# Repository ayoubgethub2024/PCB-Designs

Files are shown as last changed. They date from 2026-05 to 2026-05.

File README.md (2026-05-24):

## PCB Specifications

| Parameter | Specification |
|---|---|
| Microcontroller 1 | ATmega328P (DIP-28 or SMD) |
| Microcontroller 2 | ESP8266 (ESP-12E/F module) |
| Input Voltage | 12-24V DC (industrial standard) |
| Regulated Output | 5V @ 2A, 3.3V @ 800mA |
| Digital Inputs | 6x opto-isolated (24V) |
| Digital Outputs | 4x relay outputs (10A 250VAC) |
| Analog Inputs | 4x (0-5V / 4-20mA selectable) |
| Communication | UART, Modbus RS-485 (optional) |
| PCB Layers | 2-layer |
| PCB Size | 100mm x 80mm |

## Key Components

| Component | Part Number | Function |
|---|---|---|
| ATmega328P | ATMEGA328P-PU | Main sensor processor |
| ESP8266 | ESP-12E | WiFi and web server |
| Voltage Regulator | LM2596 | 12V to 5V conversion |
| LDO | AMS1117-3.3 | 5V to 3.3V for ESP |
| Optocoupler | PC817 | Input isolation |
| Relay | SRD-05VDC-SL-C | Output switching |
| RS-485 Transceiver | MAX485 | Modbus communication |

## File Descriptions

| File | Description |
|---|---|
| `schematic.pdf` | Complete circuit schematic |
| `pcb_layout.pdf` | PCB layout (top and bottom layers) |
| `gerber_files.zip` | Manufacturing files for PCB fabrication |
| `BOM.csv` | Bill of Materials with part numbers |
| `pcb_render.png` | 3D render of the PCB |

## How to View/Edit

### View Schematics/PCB
1. Download the PDF files
2. Open with any PDF viewer

### Edit (requires EDA software)
- **KiCad** (free, open-source)
- **Altium Designer**
- **EAGLE** (Autodesk)
- **Proteus**

### Order PCBs
1. Download `gerber_files.zip`
2. Upload to PCB manufacturer (JLCPCB, PCBWay, Seeed Studio)
3. Use `BOM.csv` for component procurement

## Production Notes

- 500+ units manufactured and deployed
- Designed for industrial environment (noise immunity, isolation)
- Wide operating temperature range: -20°C to +70°C
- Overvoltage and reverse polarity protection on power input

## Version History

| Version | Date | Changes |
|---|---|---|
| v1.0 | 2023 | Initial production release – 500+ units |
| v2.0 | 2024 | Added ESD protection, improved grounding, optional RS-485 |

## Related Repositories

- [ESP8266 Firmware](https://github.com/ayoubgethub2024/embedded-industrial-automation)
- [ATmega328 Firmware](https://github.com/ayoubgethub2024/embedded-industrial-automation/tree/main/atmega328-firmware)
- [PLC Programs](https://github.com/ayoubgethub2024/PLC-industrial-automation)

## Author

Embedded Systems & Industrial Automation Engineer

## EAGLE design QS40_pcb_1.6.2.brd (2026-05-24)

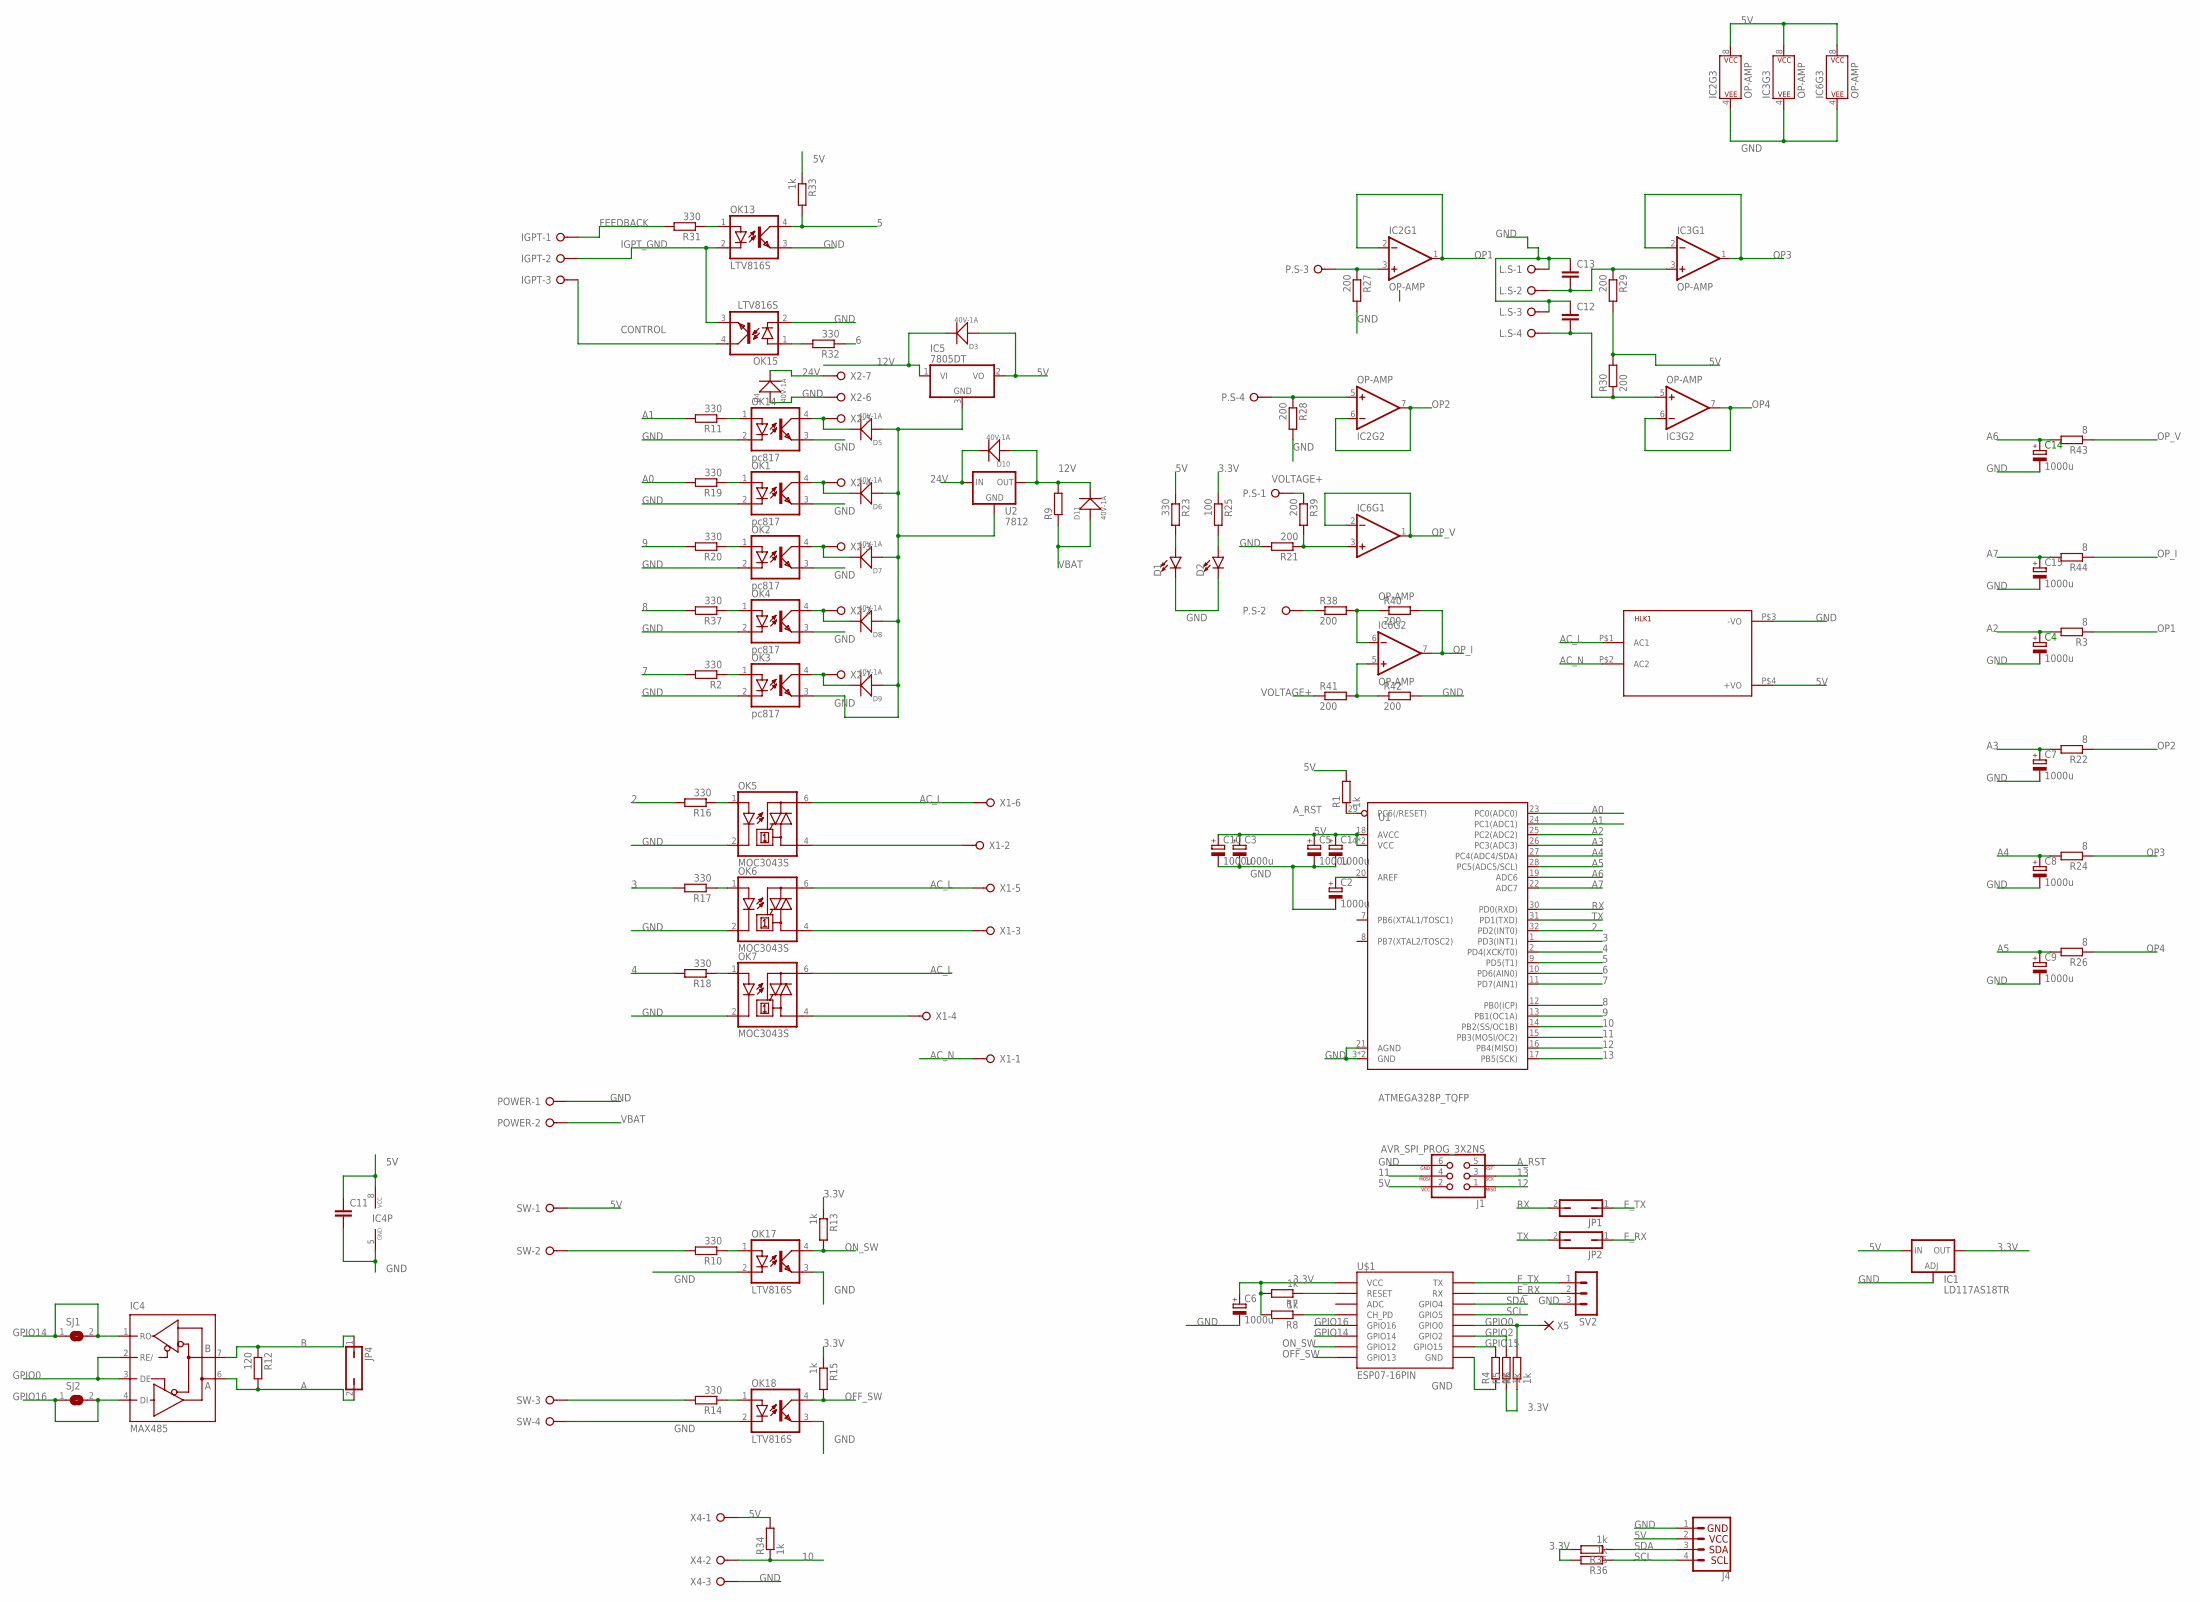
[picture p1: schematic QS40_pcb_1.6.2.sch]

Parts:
C1, C2, C3, C4, C5, C6, C7, C8, C9, C10, C14, C15: 1000u; UD-8X10_NICHICON
C11: C-EUC1206K; C1206K
C12, C13: C-EUC1206; C1206
D1, D2: LED-FKIT-1206; FKIT-LED-1206
D3, D4, D5, D6, D7, D8, D9, D10, D11: 40V-1A; DO-214AC
HLK1: HLK-PM013W; HLK-PM01
IC1: LD117AS18TR; SOT223
IC2, IC3, IC6: OP-AMP; SO08
IC4: MAX485; SO08
IC5: 7805DT; TO252
IGPT: W237-03P; W237-133
J1: AVR_SPI_PROG_3X2NS; 2X3-NS
J4: I2C_STANDARD_NO_SILK; 1X04_NO_SILK
JP1, JP2, JP4: JP1Q; JP1
L.S: W237-04P; W237-4P
OK1, OK2, OK3, OK4, OK14: pc817; DIL4-SMD
OK5, OK6, OK7: MOC3043S; DIL6-SMD
OK13, OK15, OK17, OK18: LTV816S; DIL4-SMD
P.S: W237-04P; W237-4P
POWER: W237-02P; W237-132
R1, R4, R5, R6, R7, R8, R13, R15, R33, R34, R35, R36: 1k; R1206W
R2, R10, R11, R14, R16, R17, R18, R19, R20, R23, R31, R32, R37: 330; R1206W
R3, R22, R24, R26, R43, R44: 8; R1206W
R9: R-EU_R5025; R5025
R12: 120; R1206W
R21, R27, R28, R38, R39, R40, R41, R42: 200; R1206
R25: 100; R1206W
R29, R30: 200; R1206W
SJ1, SJ2: SJ
SV2: MA03-1
SW: W237-04P; W237-4P
U1: ATMEGA328P_TQFP; TQFP32-08
U2: 7812; TO-252
U$1: ESP07-16PIN; ESP07
X1: W237-06P; W237-6P
X2: W237-07P; W237-7P
X4: W237-03P; W237-133
X5: PAD-1.00-2.00

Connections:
2: R16.2, U1.32 (PD2(INT0))
3: R17.2, U1.1 (PD3(INT1))
3.3V: C6.+, IC1.4 (OUT), R5.1, R6.1, R7.2, R8.2, R13.1, R15.1, R25.1, R35.2, R36.2, U$1.VCC
4: R18.2, U1.2 (PD4(XCK/T0))
5: OK13.4 (COL), R33.2, U1.9 (PD5(T1))
5V: C1.+, C3.+, C5.+, C10.+, C11.1, D3.1 (+), HLK1.P$4 (+VO), IC1.3 (IN), IC2.8 (P$V+), IC3.8 (P$V+), IC4.8 (VCC), IC5.2 (VO), IC6.8 (P$V+), J1.2, J4.2, R1.2, R23.1, R29.2, R30.2, R33.1, R34.2, SW.1, U1.4 (VCC), U1.6 (VCC), U1.18 (AVCC), X4.1
6: R32.1, U1.10 (PD6(AIN0))
7: R2.2, U1.11 (PD7(AIN1))
8: R37.2, U1.12 (PB0(ICP))
9: R20.2, U1.13 (PB1(OC1A))
10: R34.1, U1.14 (PB2(SS/OC1B)), X4.2
11: J1.4, U1.15 (PB3(MOSI/OC2))
12: J1.1, U1.16 (PB4(MISO))
12V: D3.2 (-), D10.1 (+), D11.2 (-), IC5.1 (VI), R9.2, U2.2 (OUT)
13: J1.3, U1.17 (PB5(SCK))
24V: D4.2 (-), D10.2 (-), U2.1 (IN), X2.7
A: IC4.6 (A), JP4.2, R12.2
A0: R19.2, U1.23 (PC0(ADC0))
A1: R11.2, U1.24 (PC1(ADC1))
A2: C4.+, R3.2, U1.25 (PC2(ADC2))
A3: C7.+, R22.2, U1.26 (PC3(ADC3))
A4: C8.+, R24.2, U1.27 (PC4(ADC4/SDA))
A5: C9.+, R26.2, U1.28 (PC5(ADC5/SCL))
A6: C14.+, R43.2, U1.19 (ADC6)
A7: C15.+, R44.2, U1.22 (ADC7)
AC_L: HLK1.P$1 (AC1), OK5.6 (A2), OK6.6 (A2), OK7.6 (A2), X1.5, X1.6
AC_N: HLK1.P$2 (AC2), X1.1
A_RST: J1.5, R1.1, U1.29 (PC6(/RESET))
B: IC4.7 (B), JP4.1, R12.1
CONTROL: IGPT.3, OK15.4 (COL)
E_RX: JP2.1, SV2.2, U$1.RX
E_TX: JP1.1, SV2.1, U$1.TX
FEEDBACK: IGPT.1, R31.2
GND: C1.-, C2.-, C3.-, C4.-, C5.-, C6.-, C7.-, C8.-, C9.-, C10.-, C11.2, C12.1, C13.1, C14.-, C15.-, D1.C, D2.C, D4.1 (+), D5.1 (+), D6.1 (+), D7.1 (+), D8.1 (+), D9.1 (+), HLK1.P$3 (-VO), IC1.1 (ADJ), IC2.4 (P$V-), IC3.4 (P$V-), IC4.5 (GND), IC5.3 (GND), IC6.4 (P$V-), J1.6, J4.1, L.S.1, L.S.3, OK1.2 (C), OK1.3 (EMIT), OK2.2 (C), OK2.3 (EMIT), OK3.2 (C), OK3.3 (EMIT), OK4.2 (C), OK4.3 (EMIT), OK5.2 (C), OK6.2 (C), OK7.2 (C), OK13.3 (EMIT), OK14.2 (C), OK14.3 (EMIT), OK15.2 (C), OK17.2 (C), OK17.3 (EMIT), OK18.2 (C), OK18.3 (EMIT), POWER.1, R4.1, R21.2, R27.2, R28.2, R42.2, SV2.3, SW.4, U1.3 (GND), U1.5 (GND), U1.21 (AGND), U2.3 (GND), U$1.GND, X2.6, X4.3
GPIO0: IC4.2 (RE/), IC4.3 (DE), R6.2, U$1.GPIO0, X5.1
GPIO2: R5.2, U$1.GPIO2
GPIO14: IC4.1 (RO), SJ1.1, SJ1.2, U$1.GPIO14
GPIO15: R4.2, U$1.GPIO15
GPIO16: IC4.4 (DI), SJ2.1, SJ2.2, U$1.GPIO16
IGPT_GND: IGPT.2, OK13.2 (C), OK15.3 (EMIT)
unnamed: OK5.4 (A1), X1.2
unnamed: IC2.3 (+IN), P.S.3, R27.1
unnamed: R7.1, U$1.REST (RESET)
unnamed: R8.1, U$1.CH_PD
unnamed: C2.+, U1.20 (AREF)
unnamed: OK7.4 (A1), X1.4
unnamed: OK14.1 (A), R11.1
unnamed: OK3.1 (A), R2.1
unnamed: OK1.1 (A), R19.1
unnamed: OK6.4 (A1), X1.3
unnamed: OK2.1 (A), R20.1
unnamed: OK4.1 (A), R37.1
unnamed: C13.2, IC3.3 (+IN), L.S.2, R29.1
unnamed: D1.A, R23.2
unnamed: D2.A, R25.2
unnamed: D5.2 (-), OK14.4 (COL), X2.5
unnamed: D6.2 (-), OK1.4 (COL), X2.4
unnamed: D7.2 (-), OK2.4 (COL), X2.3
unnamed: C12.2, IC3.5 (+IN), L.S.4, R30.1
unnamed: OK15.1 (A), R32.2
unnamed: IC2.5 (+IN), P.S.4, R28.1
unnamed: D8.2 (-), OK4.4 (COL), X2.2
unnamed: D9.2 (-), OK3.4 (COL), X2.1
unnamed: OK17.1 (A), R10.1
unnamed: P.S.2, R38.1
unnamed: OK5.1 (A), R16.1
unnamed: R10.2, SW.2
unnamed: OK18.1 (A), R14.1
unnamed: IC6.5 (+IN), R41.2, R42.1
unnamed: IC6.3 (+IN), R21.1, R39.2
unnamed: OK6.1 (A), R17.1
unnamed: IC6.6 (-IN), R38.2, R40.1
unnamed: R14.2, SW.3
unnamed: OK7.1 (A), R18.1
unnamed: OK13.1 (A), R31.1
OFF_SW: OK18.4 (COL), R15.2, U$1.GPIO13
ON_SW: OK17.4 (COL), R13.2, U$1.GPIO12
OP1: IC2.1 (OUT), IC2.2 (-IN), R3.1
OP2: IC2.6 (-IN), IC2.7 (OUT), R22.1
OP3: IC3.1 (OUT), IC3.2 (-IN), R24.1
OP4: IC3.6 (-IN), IC3.7 (OUT), R26.1
OP_I: IC6.7 (OUT), R40.2, R44.1
OP_V: IC6.1 (OUT), IC6.2 (-IN), R43.1
RX: JP1.2, U1.30 (PD0(RXD))
SCL: J4.4, R36.1, U$1.GPIO5
SDA: J4.3, R35.1, U$1.GPIO4
TX: JP2.2, U1.31 (PD1(TXD))
VBAT: D11.1 (+), POWER.2, R9.1
VOLTAGE+: P.S.1, R39.1, R41.1

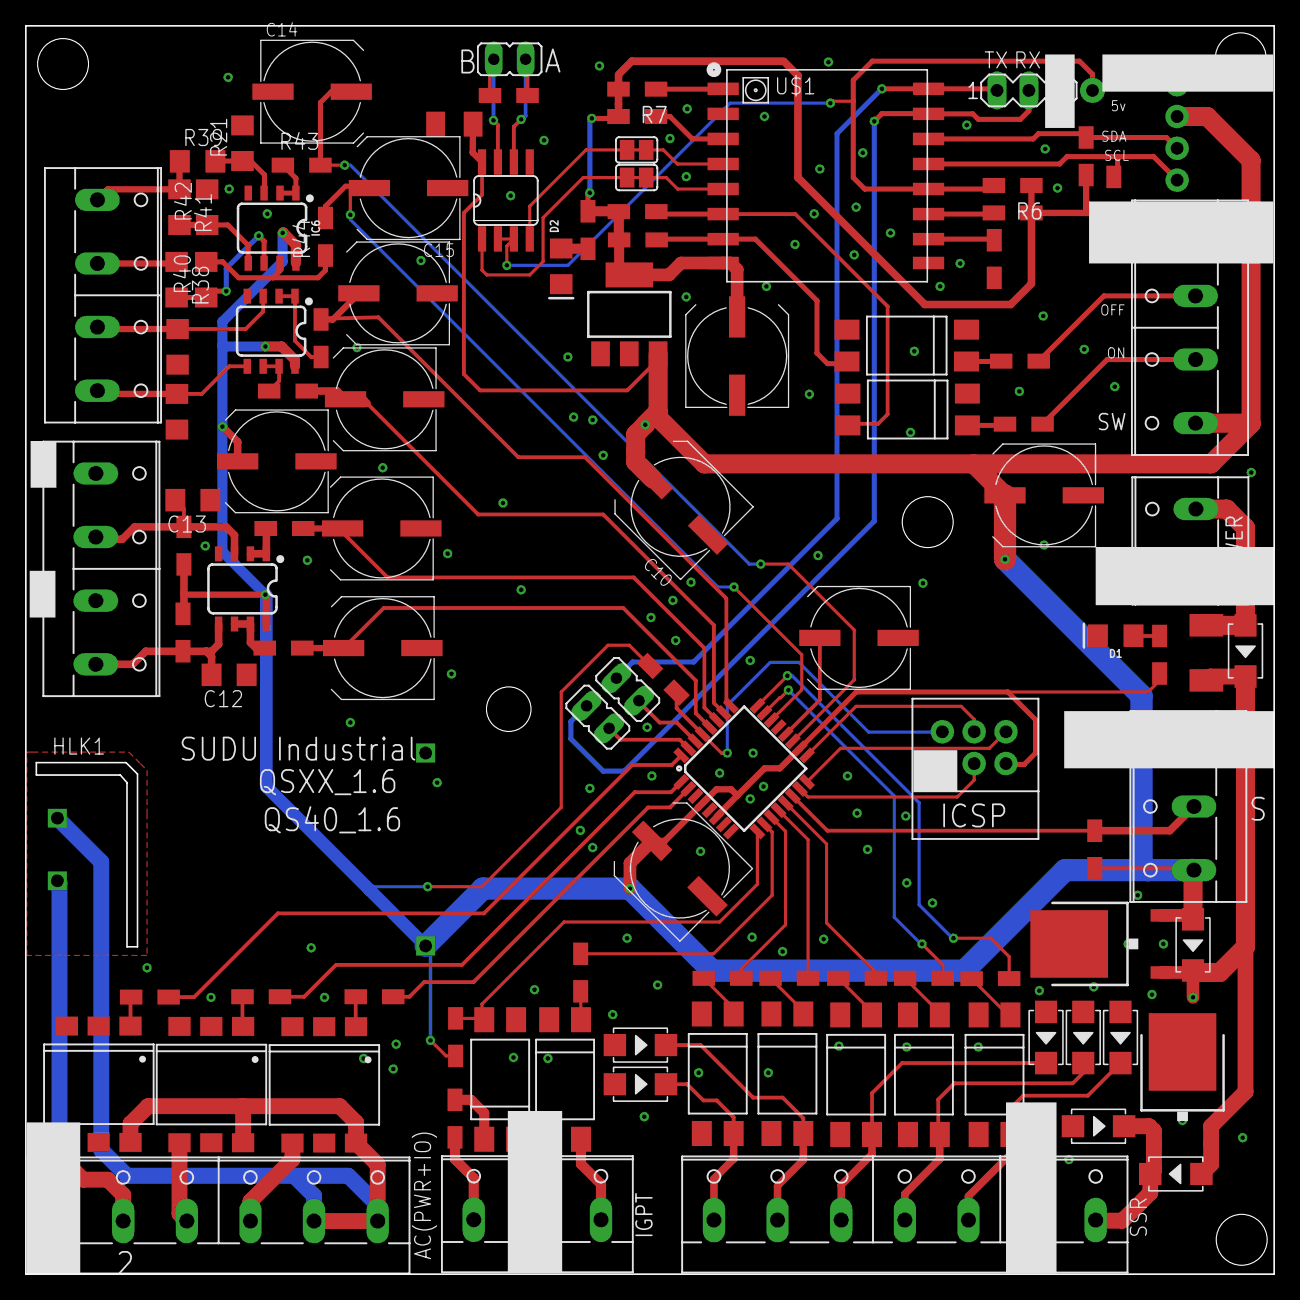
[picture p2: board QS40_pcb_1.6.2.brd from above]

Board: 2 copper layers, 99.7 x 99.7 mm, 109 parts (0 on the bottom side), 89 nets.

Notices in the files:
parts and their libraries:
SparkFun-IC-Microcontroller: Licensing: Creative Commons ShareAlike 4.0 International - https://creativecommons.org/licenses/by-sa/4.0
